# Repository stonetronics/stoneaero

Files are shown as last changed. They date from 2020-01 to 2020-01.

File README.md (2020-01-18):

# stoneaero
Flight controller + transmitter hardware using Arduino Nano, NRF24L01, MPU6050, etc

basic transmitter/receiver code is contained in these folders:

* transmitter
  * basic joystick operation
  * throttle on potentiometer

* receiver
  * basic servo signal forwarding from rf module
  * automatic throttle cut and circular descent when there is no signal received for 1.5s

more advanced functions are contained in receevur/trunsmeetur

* hw
  * eagle files for both pcbs
  * receevur
    * ATmega328p
    * 7 servo channels
    * 3S lipo voltage measurement
    * current measurement
    * MPU9250/MPU6050 header
    * NRF24L01+PA+LNA module
  * trunsmeetur
    * Arduino Mega
    * 16x2 generic lcd
    * buttons for lcd menu
    * NRF24L01+PA+LNA module
    * pinheaders for connecting joysticks, switches etc
    * designed to replace the electronics on a "modelcraft N-6" transmitter

* receevur
  * servo signals
    * airbrake mode for ailerons
  * current/voltage reporting

* trunsmeetur
  * lcd display
    * current/voltage report display
    * joystick settings
  * controls for servo signals

feel free to edit

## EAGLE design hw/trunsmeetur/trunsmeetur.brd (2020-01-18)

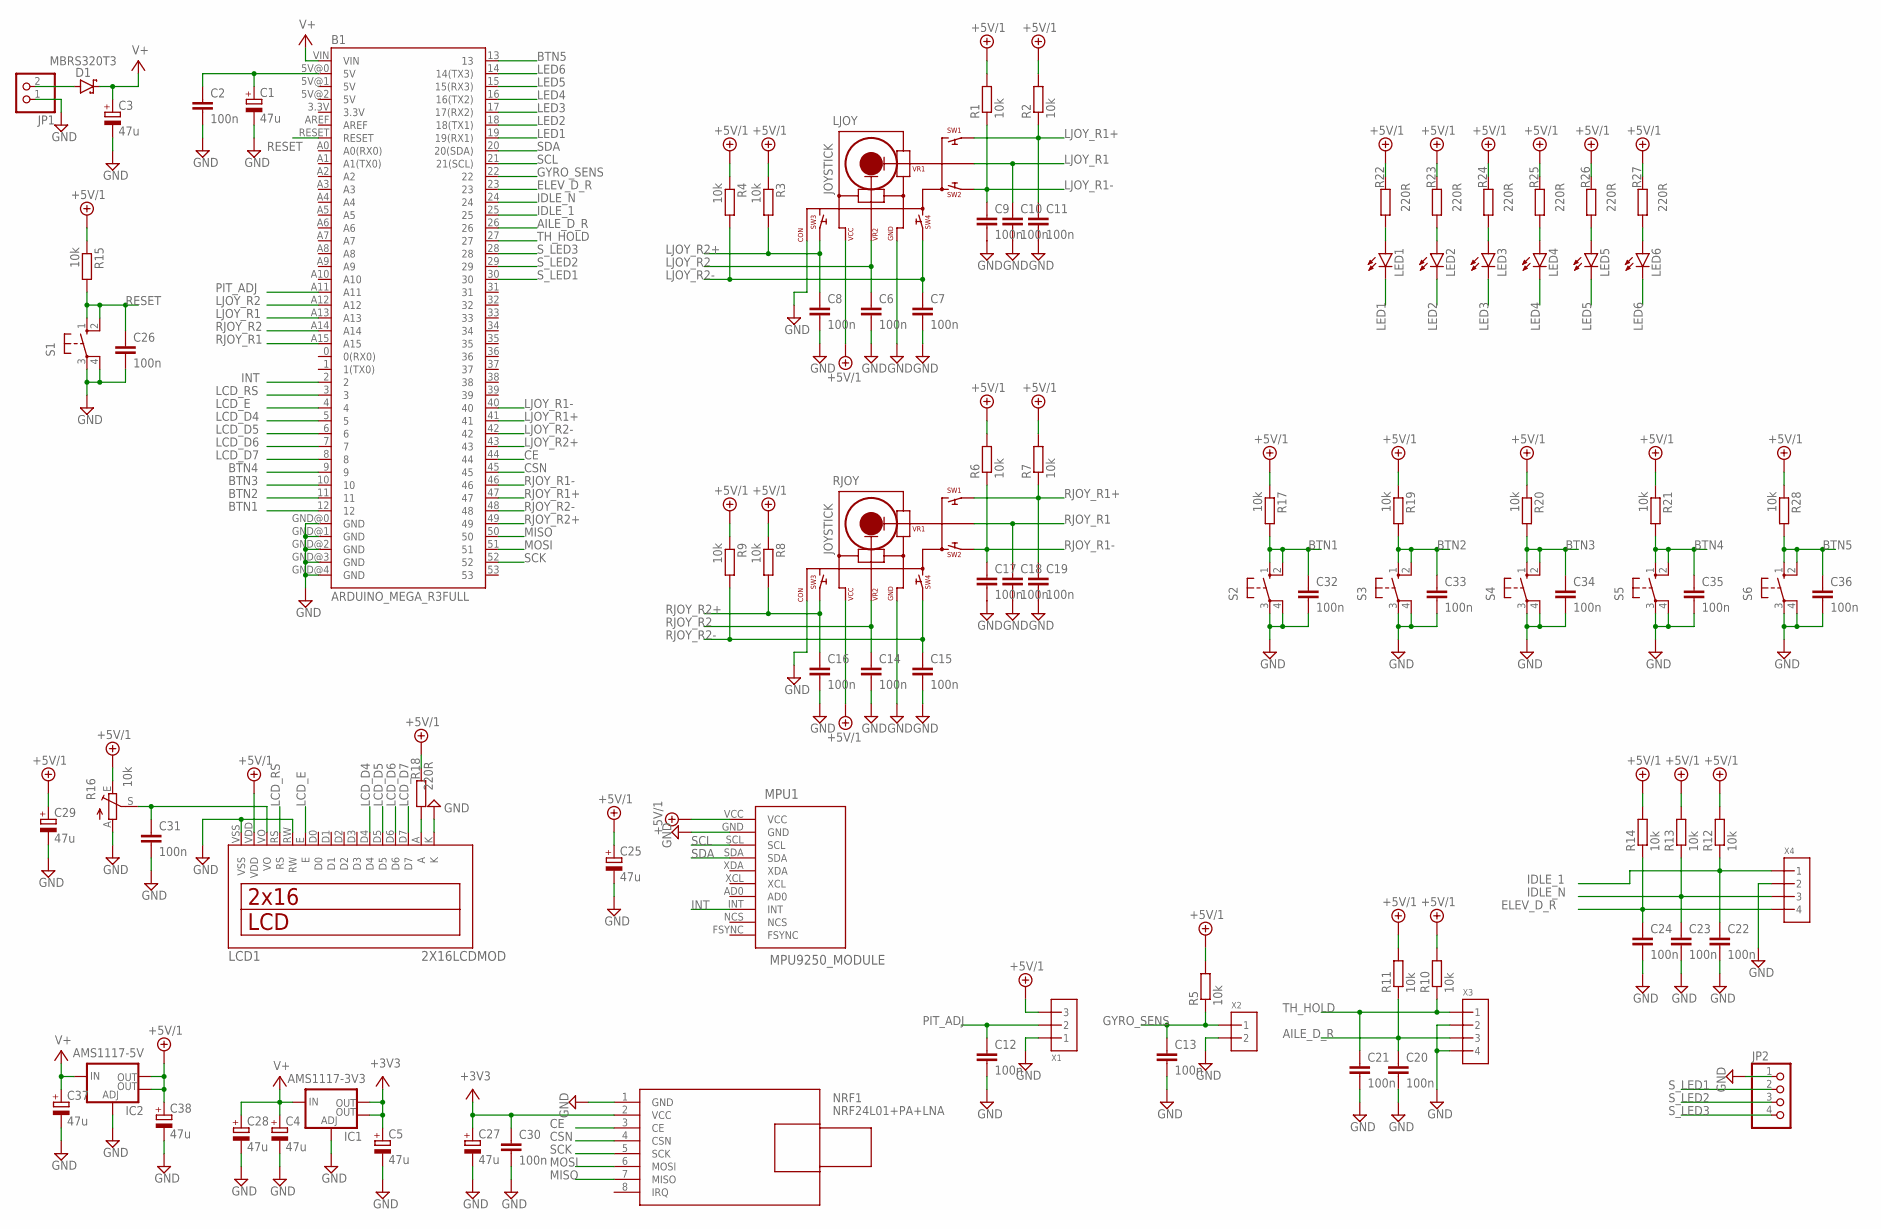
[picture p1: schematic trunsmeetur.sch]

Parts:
B1: ARDUINO_MEGA_R3FULL; ARDUINO_MEGA
C1, C3, C4, C5, C25, C27, C28, C29, C37, C38: 47u; 153CLV-0605
C2, C6, C7, C8, C9, C10, C11, C12, C13, C14, C15, C16, C17, C18, C19, C20, C21, C22, C23, C24, C26, C30, C31, C32, C33, C34, C35, C36: 100n; C0805
D1: MBRS320T3; SMC
IC1: AMS1117-3V3; SOT223
IC2: AMS1117-5V; SOT223
JP1: PINHD-1X2; 1X02
JP2: PINHD-1X4; 1X04
LCD1: 2X16LCDMOD; LCD16X2MOD
LED1, LED2, LED3, LED4, LED5, LED6: LEDCHIPLED_0805; CHIPLED_0805
LJOY: JOYSTICK; JOYSTICKCONNECTOR
MPU1: MPU9250_MODULE
NRF1: NRF24L01+PA+LNA; WIRELESS-NRF24L01-PA-EXT
R1, R2, R3, R4, R5, R6, R7, R8, R9, R10, R11, R12, R13, R14, R15, R17, R19, R20, R21, R28: 10k; M0805
R16: 10k; CA9V
R18, R22, R23, R24, R25, R26, R27: 220R; M0805
RJOY: JOYSTICK; JOYSTICKCONNECTOR
S1, S2, S3, S4, S5, S6: 10-XX; B3F-10XX
X1: 3PIN; 3PINCONNECTOR
X2: 2PIN; 2PINCONNECTOR
X3, X4: 4PIN; 4PINCONNECTOR

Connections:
+3V3: C5.+, C27.+, C30.1, IC1.2 (OUT), IC1.4 (OUT), NRF1.2 (VCC)
+5V/1: C25.+, C29.+, C38.+, IC2.2 (OUT), IC2.4 (OUT), LCD1.VDD, LJOY.VCC, MPU1.VCC, R1.2, R2.2, R3.1, R4.1, R5.2, R6.2, R7.2, R8.1, R9.1, R10.2, R11.2, R12.2, R13.2, R14.2, R15.1, R16.E, R17.1, R18.1, R19.1, R20.1, R21.1, R22.1, R23.1, R24.1, R25.1, R26.1, R27.1, R28.1, RJOY.VCC, X1.3
AILE_D_R: B1.26, C20.1, R11.1, X3.3
BTN1: B1.12, C32.1, R17.2, S2.1 (S), S2.2 (S1)
BTN2: B1.11, C33.1, R19.2, S3.1 (S), S3.2 (S1)
BTN3: B1.10, C34.1, R20.2, S4.1 (S), S4.2 (S1)
BTN4: B1.9, C35.1, R21.2, S5.1 (S), S5.2 (S1)
BTN5: B1.13, C36.1, R28.2, S6.1 (S), S6.2 (S1)
CE: B1.44, NRF1.3 (CE)
CSN: B1.45, NRF1.4 (CSN)
ELEV_D_R: B1.23, C24.1, R14.1, X4.4
GND: B1.GND@0 (GND), B1.GND@1 (GND), B1.GND@2 (GND), B1.GND@3 (GND), B1.GND@4 (GND), C1.-, C2.2, C3.-, C4.-, C5.-, C6.2, C7.2, C8.2, C9.2, C10.2, C11.2, C12.2, C13.2, C14.2, C15.2, C16.2, C17.2, C18.2, C19.2, C20.2, C21.2, C22.2, C23.2, C24.2, C25.-, C26.2, C27.-, C28.-, C29.-, C30.2, C31.2, C32.2, C33.2, C34.2, C35.2, C36.2, C37.-, C38.-, IC1.1 (ADJ), IC2.1 (ADJ), JP1.1, JP2.1, LCD1.K, LCD1.RW, LCD1.VSS, LJOY.CON, LJOY.GND, MPU1.GND, NRF1.1 (GND), R16.A, RJOY.CON, RJOY.GND, S1.3, S1.4 (P1), S2.3, S2.4 (P1), S3.3, S3.4 (P1), S4.3, S4.4 (P1), S5.3, S5.4 (P1), S6.3, S6.4 (P1), X1.1, X2.2, X3.2, X3.4, X4.2
GYRO_SENS: B1.22, C13.1, R5.1, X2.1
IDLE_1: B1.25, C22.1, R12.1, X4.1
IDLE_N: B1.24, C23.1, R13.1, X4.3
INT: B1.2, MPU1.INT
LCD_D4: B1.5, LCD1.D4
LCD_D5: B1.6, LCD1.D5
LCD_D6: B1.7, LCD1.D6
LCD_D7: B1.8, LCD1.D7
LCD_E: B1.4, LCD1.E
LCD_RS: B1.3, LCD1.RS
LED1: B1.19 (19(RX1)), LED1.C
LED2: B1.18 (18(TX1)), LED2.C
LED3: B1.17 (17(RX2)), LED3.C
LED4: B1.16 (16(TX2)), LED4.C
LED5: B1.15 (15(RX3)), LED5.C
LED6: B1.14 (14(TX3)), LED6.C
LJOY_R1: B1.A13, C10.1, LJOY.VR1
LJOY_R1+: B1.41, C11.1, LJOY.SW1, R2.1
LJOY_R1-: B1.40, C9.1, LJOY.SW2, R1.1
LJOY_R2: B1.A12, C6.1, LJOY.VR2
LJOY_R2+: B1.43, C8.1, LJOY.SW3, R3.2
LJOY_R2-: B1.42, C7.1, LJOY.SW4, R4.2
MISO: B1.50, NRF1.7 (MISO)
MOSI: B1.51, NRF1.6 (MOSI)
unnamed: C31.1, LCD1.VO, R16.S
unnamed: D1.A, JP1.2
unnamed: LCD1.A, R18.2
unnamed: LED1.A, R22.2
unnamed: LED2.A, R23.2
unnamed: LED3.A, R24.2
unnamed: LED4.A, R25.2
unnamed: LED5.A, R26.2
unnamed: LED6.A, R27.2
unnamed: B1.5V@0 (5V), C1.+, C2.1
PIT_ADJ: B1.A11, C12.1, X1.2
RESET: B1.RESET, C26.1, R15.2, S1.1 (S), S1.2 (S1)
RJOY_R1: B1.A15, C18.1, RJOY.VR1
RJOY_R1+: B1.47, C19.1, R7.1, RJOY.SW1
RJOY_R1-: B1.46, C17.1, R6.1, RJOY.SW2
RJOY_R2: B1.A14, C14.1, RJOY.VR2
RJOY_R2+: B1.49, C16.1, R8.2, RJOY.SW3
RJOY_R2-: B1.48, C15.1, R9.2, RJOY.SW4
SCK: B1.52, NRF1.5 (SCK)
SCL: B1.21 (21(SCL)), MPU1.SCL
SDA: B1.20 (20(SDA)), MPU1.SDA
S_LED1: B1.30, JP2.2
S_LED2: B1.29, JP2.3
S_LED3: B1.28, JP2.4
TH_HOLD: B1.27, C21.1, R10.1, X3.1
V+: B1.VIN, C3.+, C4.+, C28.+, C37.+, D1.C, IC1.3 (IN), IC2.3 (IN)

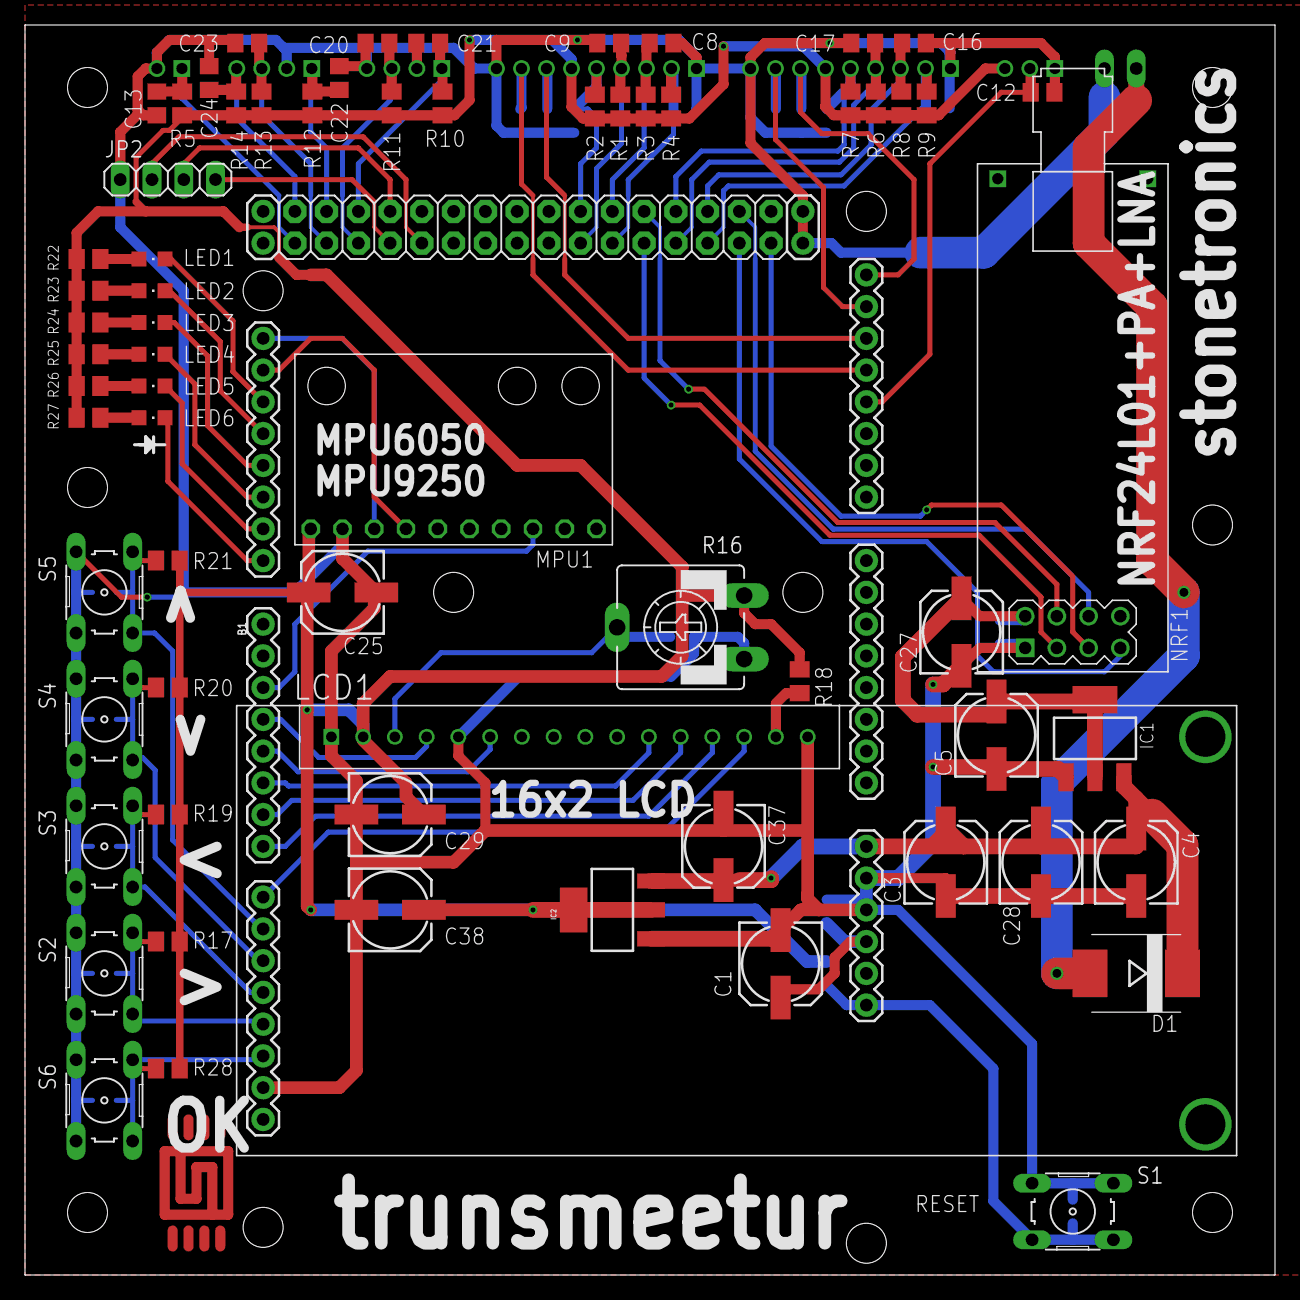
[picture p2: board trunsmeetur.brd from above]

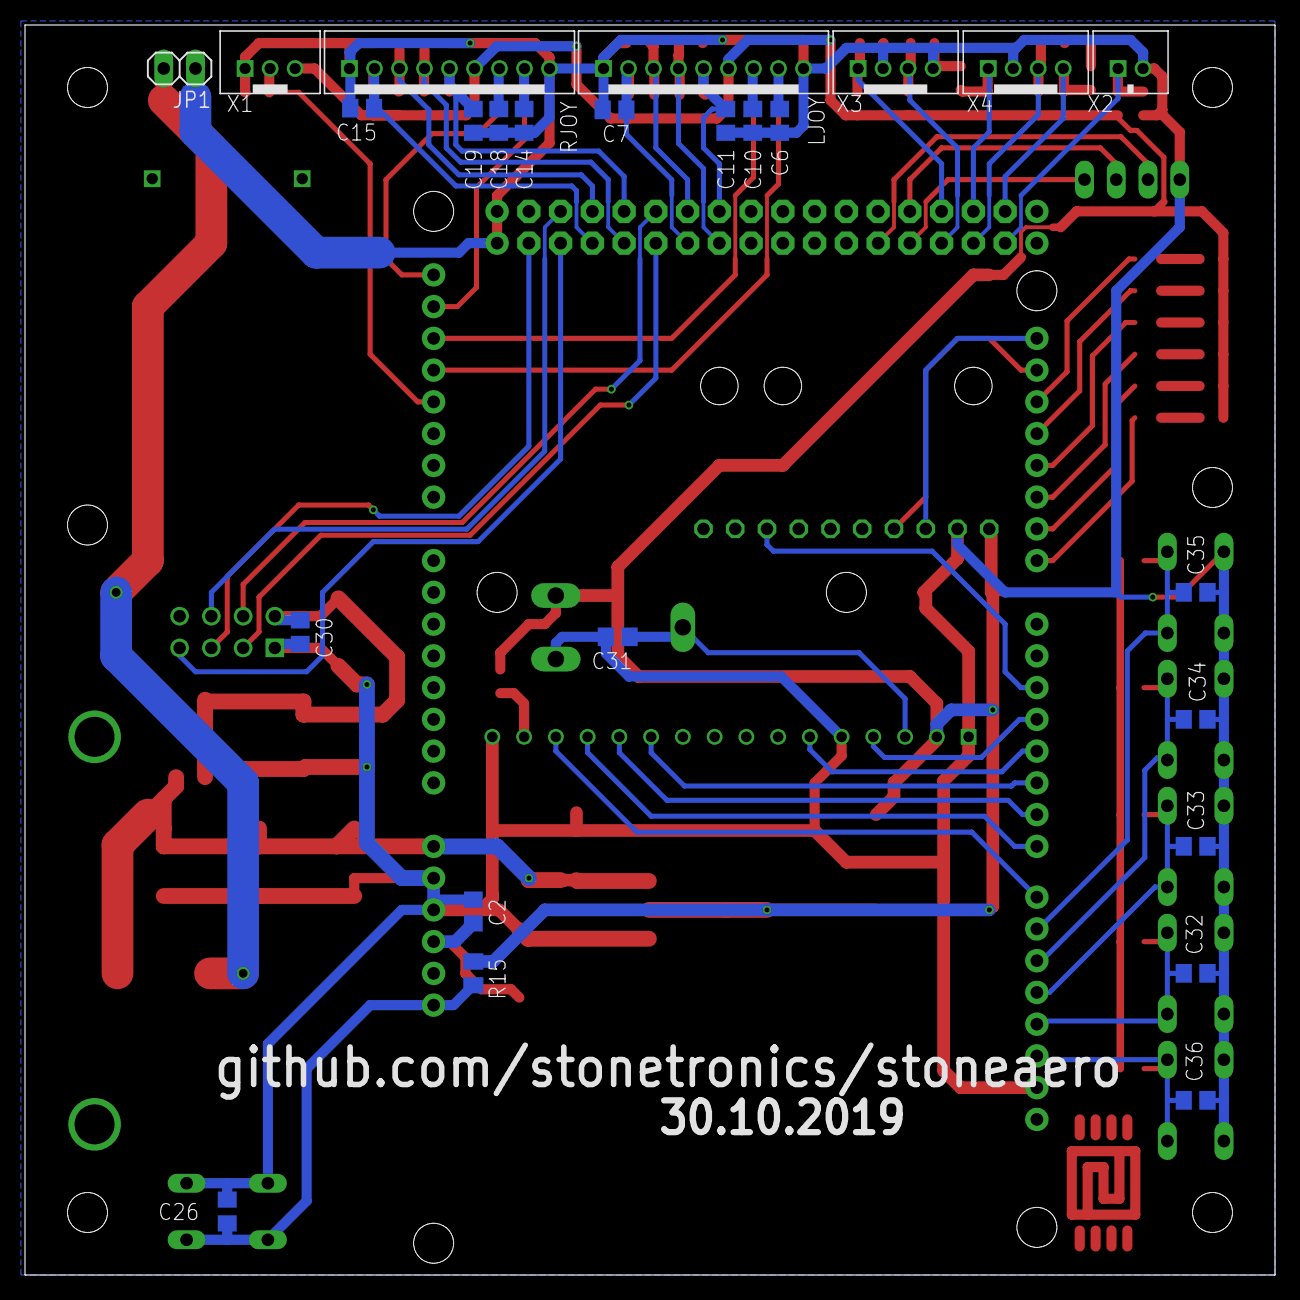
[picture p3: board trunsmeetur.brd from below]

Board: 2 copper layers, 100.0 x 100.0 mm, 93 parts (25 on the bottom side), 62 nets.

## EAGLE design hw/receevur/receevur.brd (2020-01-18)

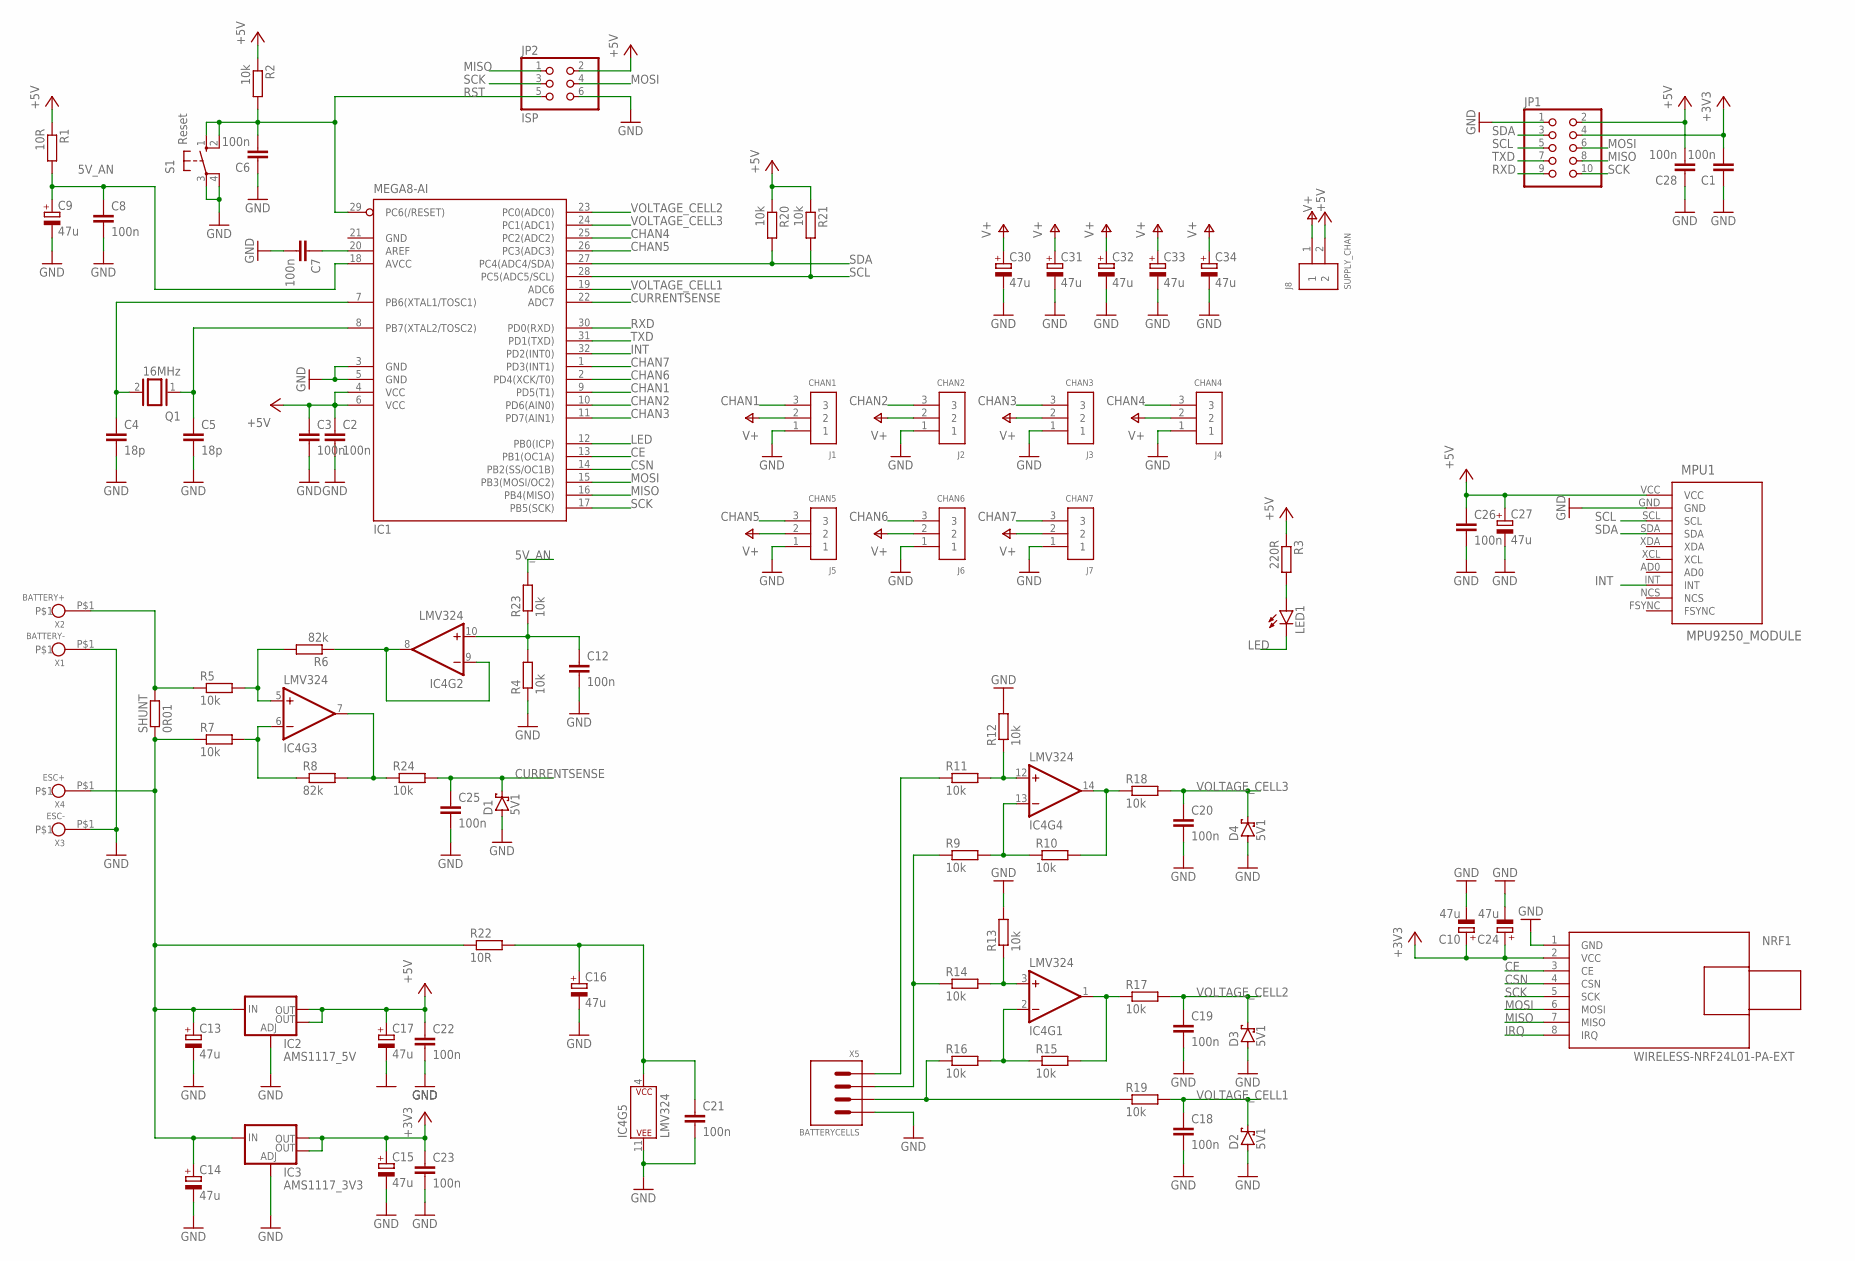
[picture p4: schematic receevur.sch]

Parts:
C1, C2, C3, C6, C7, C8, C12, C18, C19, C20, C21, C22, C23, C25, C26, C28: 100n; C0805
C4, C5: 18p; C0805
C9, C10, C13, C14, C15, C16, C17, C24, C27, C30, C31, C32, C33, C34: 47u; 153CLV-0405
D1, D2, D3, D4: 5V1; SOD323_ST
IC1: MEGA8-AI; TQFP32-08
IC2: AMS1117_5V; SOT223
IC3: AMS1117_3V3; SOT223
IC4: LMV324; SO14
J1: CHAN1; 61300311121
J2: CHAN2; 61300311121
J3: CHAN3; 61300311121
J4: CHAN4; 61300311121
J5: CHAN5; 61300311121
J6: CHAN6; 61300311121
J7: CHAN7; 61300311121
J8: SUPPLY_CHAN; 61300211121
JP1: PINHD-2X5; 2X05
JP2: ISP; 2X03
LED1: LEDCHIP-LED0805; CHIP-LED0805
MPU1: MPU9250_MODULE
NRF1: WIRELESS-NRF24L01-PA-EXT
Q1: 16MHz; QS
R1, R22: 10R; R0805
R2, R4, R5, R7, R9, R10, R11, R12, R13, R14, R15, R16, R17, R18, R19, R20, R21, R23, R24: 10k; R0805
R3: 220R; R0805
R6, R8: 82k; R0805
S1: Reset; B3F-10XX
SHUNT: 0R01; R2512
X1: BATTERY-; SMDSOLDERPAD_5X7
X2: BATTERY+; SMDSOLDERPAD_5X7
X3: ESC-; SMDSOLDERPAD_5X7
X4: ESC+; SMDSOLDERPAD_5X7
X5: BATTERYCELLS; CELLJACK

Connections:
5V_AN: C8.1, C9.+, IC1.18 (AVCC), R1.2, R23.2
+3V3: C1.2, C10.+, C15.+, C23.1, C24.+, IC3.2 (OUT), IC3.4 (OUT), JP1.4, NRF1.2 (VCC)
+5V: C2.1, C3.1, C17.+, C22.1, C26.1, C27.+, C28.2, IC1.4 (VCC), IC1.6 (VCC), IC2.2 (OUT), IC2.4 (OUT), J8.2, JP1.2, JP2.2, MPU1.VCC, R1.1, R2.1, R3.1, R20.1, R21.1
CE: IC1.13 (PB1(OC1A)), NRF1.3 (CE)
CHAN1: IC1.9 (PD5(T1)), J1.3
CHAN2: IC1.10 (PD6(AIN0)), J2.3
CHAN3: IC1.11 (PD7(AIN1)), J3.3
CHAN4: IC1.25 (PC2(ADC2)), J4.3
CHAN5: IC1.26 (PC3(ADC3)), J5.3
CHAN6: IC1.2 (PD4(XCK/T0)), J6.3
CHAN7: IC1.1 (PD3(INT1)), J7.3
CSN: IC1.14 (PB2(SS/OC1B)), NRF1.4 (CSN)
CURRENTSENSE: C25.1, D1.C, IC1.22 (ADC7), R24.2
GND: C1.1, C2.2, C3.2, C4.2, C5.2, C6.1, C7.2, C8.2, C9.-, C10.-, C12.2, C13.-, C14.-, C15.-, C16.-, C17.-, C18.2, C19.2, C20.2, C21.2, C22.2, C23.2, C24.-, C25.2, C26.2, C27.-, C28.1, C30.-, C31.-, C32.-, C33.-, C34.-, D1.A, D2.A, D3.A, D4.A, IC1.3 (GND), IC1.5 (GND), IC1.21 (GND), IC2.1 (ADJ), IC3.1 (ADJ), IC4.11 (P$V-), J1.1, J2.1, J3.1, J4.1, J5.1, J6.1, J7.1, JP1.1, JP2.6, MPU1.GND, NRF1.1 (GND), R4.1, R12.2, R13.2, S1.3, S1.4 (P1), X1.P$1, X3.P$1, X5.P$1
INT: IC1.32 (PD2(INT0)), MPU1.INT
IRQ: NRF1.8 (IRQ)
LED: IC1.12 (PB0(ICP)), LED1.C
MISO: IC1.16 (PB4(MISO)), JP1.8, JP2.1, NRF1.7 (MISO)
MOSI: IC1.15 (PB3(MOSI/OC2)), JP1.6, JP2.4, NRF1.6 (MOSI)
unnamed: C4.1, IC1.7 (PB6(XTAL1/TOSC1)), Q1.2
unnamed: C5.1, IC1.8 (PB7(XTAL2/TOSC2)), Q1.1
unnamed: C7.1, IC1.20 (AREF)
unnamed: LED1.A, R3.2
unnamed: C13.+, C14.+, IC2.3 (IN), IC3.3 (IN), R7.1, R22.1, SHUNT.1, X4.P$1
unnamed: IC4.12 (+IN), R11.2, R12.1
unnamed: C16.+, C21.1, IC4.4 (P$V+), R22.2
unnamed: R5.1, SHUNT.2, X2.P$1
unnamed: IC4.13 (-IN), R9.2, R10.1
unnamed: IC4.8 (OUT), IC4.9 (-IN), R6.1
unnamed: IC4.6 (-IN), R7.2, R8.1
unnamed: IC4.14 (OUT), R10.2, R18.1
unnamed: IC4.3 (+IN), R13.1, R14.2
unnamed: IC4.2 (-IN), R15.1, R16.2
unnamed: IC4.1 (OUT), R15.2, R17.1
unnamed: R11.1, X5.P$4
unnamed: R9.1, R14.1, X5.P$3
unnamed: R16.1, R19.1, X5.P$2
unnamed: C12.1, IC4.10 (+IN), R4.2, R23.1
unnamed: IC4.5 (+IN), R5.2, R6.2
N$$$: IC4.7 (OUT), R8.2, R24.1
RST: C6.2, IC1.29 (PC6(/RESET)), JP2.5, R2.2, S1.1 (S), S1.2 (S1)
RXD: IC1.30 (PD0(RXD)), JP1.9
SCK: IC1.17 (PB5(SCK)), JP1.10, JP2.3, NRF1.5 (SCK)
SCL: IC1.28 (PC5(ADC5/SCL)), JP1.5, MPU1.SCL, R21.2
SDA: IC1.27 (PC4(ADC4/SDA)), JP1.3, MPU1.SDA, R20.2
TXD: IC1.31 (PD1(TXD)), JP1.7
V+: C30.+, C31.+, C32.+, C33.+, C34.+, J1.2, J2.2, J3.2, J4.2, J5.2, J6.2, J7.2, J8.1
VOLTAGE_CELL1: C18.1, D2.C, IC1.19 (ADC6), R19.2
VOLTAGE_CELL2: C19.1, D3.C, IC1.23 (PC0(ADC0)), R17.2
VOLTAGE_CELL3: C20.1, D4.C, IC1.24 (PC1(ADC1)), R18.2

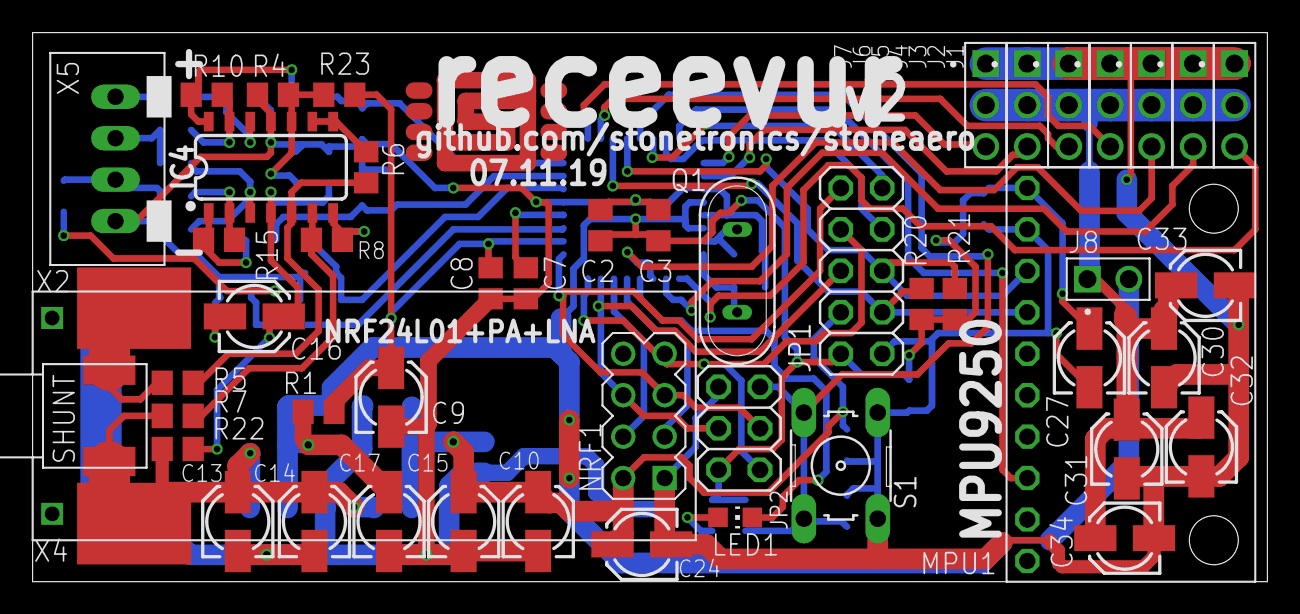
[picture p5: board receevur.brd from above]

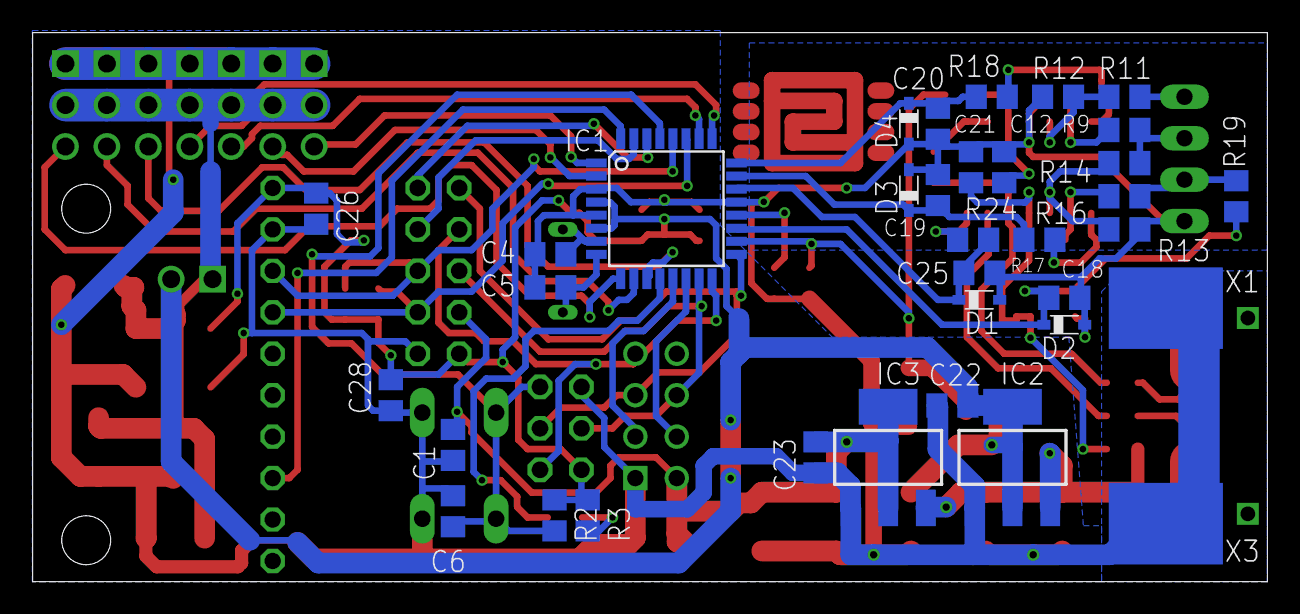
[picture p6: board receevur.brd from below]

Board: 2 copper layers, 75.7 x 33.6 mm, 85 parts (35 on the bottom side), 49 nets.

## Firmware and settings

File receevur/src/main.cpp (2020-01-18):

///avrdude upload command: avrdude -c usbasp -p m328p -u -U flash:w:firmware.hex


//Include needed Libraries at beginning
#include <Arduino.h>
#include <Servo.h>
#include "nRF24L01.h" //NRF24L01 library created by TMRh20 https://github.com/TMRh20/RF24
#include "RF24.h"
#include "SPI.h"
#include "printf.h"

#include "pindef.h"
#include "servodef.h"
#include "Messages.h"
#include "Analog.h"
#include "Monoflop.h"

#define TIMEOUT_DESCENT   2000 //ms   timeout for going into emergency mode

Analog analog;

RF24 radio(CE, CSN); // NRF24L01 used SPI pins + Pin 9 and 10 on the NANO

Monoflop monoflopDescent;
Monoflop monoflopReset;

Servo motor;
Servo rudder;
Servo elevator;
Servo aileronRight;
Servo aileronLeft;

const uint64_t commandPipe = 1; // Needs to be the same for communicating between 2 NRF24L01
const uint64_t reportPipe = 2;

Command command;
Report report;

int16_t motorOffset = 0;
int16_t rudderOffset = 0;
int16_t elevatorOffset = 0;
int16_t aileronsOffset = 0;

void setup(void){

  Serial.begin(115200);
  printf_begin();
  Serial.println("Hullo! Dis eez d receevur!");

  monoflopDescent.setHoldTime(TIMEOUT_DESCENT); //time for emergency routine

  Serial.println("initializing Servos");

  //attach servos
  motor.attach(MOTOR_PIN);
  motor.write(MOTOR_MAX);
  rudder.attach(RUDDER_PIN);
  rudder.write(90);
  elevator.attach(ELEVATOR_PIN);
  elevator.write(90);
  aileronRight.attach(AILERONRIGHT_PIN);
  aileronRight.write(90);
  aileronLeft.attach(AILERONLEFT_PIN);
  aileronLeft.write(90);

  //init led
  pinMode(LED, OUTPUT);
  //blink it
  for (uint8_t i = 0; i < 5; i++)
  {
    digitalWrite(LED, LOW);
    delay(300);
    digitalWrite(LED, HIGH);
    delay(120);
  }
  digitalWrite(LED, LOW);

  Serial.println("Initializing Analog measurements");
  analog.setCellCalibration(0, 29, 6, 0);
  analog.setCellCalibration(1, 29, 6, 0);
  analog.setCellCalibration(2, 29, 6, 0);
  analog.setCurrentCalibration(11689,101,-59255);

  Serial.println("Initializing radio");

  radio.begin(); // Start the NRF24L01
  radio.openWritingPipe(reportPipe);
  radio.openReadingPipe(1, commandPipe); //get ready to receive
  radio.setDataRate( RF24_250KBPS ) ;
  radio.setPALevel( RF24_PA_MAX ) ;
  radio.setChannel(0x34);
  radio.enableDynamicPayloads() ;
  radio.enableAckPayload();               // not used here
  radio.setRetries(0, 15);                // Smallest time between retries, max no. of retries
  radio.setAutoAck( true ) ;
  radio.printDetails();                   // Dump the configuration of the rf unit for debugging
  radio.powerUp();
  radio.startListening();
}

void loop(void){

  if (!monoflopDescent.output()) //emergency - no transmitter signal received for TIMEOUT_DESCENT
  {
    Serial.println("Hmmst! Nopheeng receevhde. Eemurgance..");
    //cut motor
    motor.write(MOTOR_MIN); //todo: does the motor need throttle for safe descent? - probably
  }



  while (radio.available())
  {
    monoflopDescent.trigger();
    radio.read(&command, sizeof(command));
    switch (command.mode)
    {
      case 'c':
        if (command.controlByte & 0x01)
        { //flaps mode
          aileronRight.write(map(((command.roll) + aileronsOffset),-90,90,AILERONRIGHT_MIN,90));
          aileronLeft.write(map((-1)*((command.roll) + aileronsOffset),-90,90,AILERONLEFT_MIN,90));
        } else { //normal mode
          aileronRight.write(map(((command.roll) + aileronsOffset),-90,90,AILERONRIGHT_MIN,AILERONRIGHT_MAX));
          aileronLeft.write(map((-1)*((command.roll) + aileronsOffset),-90,90,AILERONLEFT_MIN,AILERONLEFT_MAX));
        }
        motor.write(map(((command.throttle) + motorOffset),0,100,MOTOR_MIN,MOTOR_MAX));
        rudder.write(map(((command.yaw) + rudderOffset),-90,90,RUDDER_MIN,RUDDER_MAX));
        elevator.write(map(((command.pitch) + elevatorOffset),-90,90,ELEVATOR_MIN,ELEVATOR_MAX));
        break;

      case 'o':
        //motorOffset = command.throttle;
        rudderOffset = command.yaw;
        elevatorOffset = command.pitch;
        aileronsOffset = command.roll;

      default:
        break;
    }

    //command received and processed - transmit report package
    report.current = analog.getCurrent();
    analog.getCells(&(report.cellVoltage[0]));
    radio.stopListening();
    radio.write(&report, sizeof(report)); // Send value through NRF24L01
    radio.startListening();
  }

}

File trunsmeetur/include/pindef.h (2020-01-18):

#ifndef __PINDEF_H__
#define __PINDEF_H__


//JOYSTICKS

#define LJOY_R1       A13
#define LJOY_R1PLUS   41
#define LJOY_R1MINUS  40

#define LJOY_R2       A12
#define LJOY_R2PLUS   43
#define LJOY_R2MINUS  42

#define RJOY_R1       A15
#define RJOY_R1PLUS   47
#define RJOY_R1MINUS  46

#define RJOY_R2       A14
#define RJOY_R2PLUS   49
#define RJOY_R2MINUS  48


//PCB BUTTONS

#define BTN1    12
#define BTN2    11
#define BTN3    10
#define BTN4    9
#define BTN5    13

//readability
#define BTN_UP      BTN4
#define BTN_DOWN    BTN3
#define BTN_LEFT    BTN2
#define BTN_RIGHT   BTN1
#define BTN_OK      BTN5


//PCB LEDS (0-active)

#define LED1  19
#define LED2  18
#define LED3  17
#define LED4  16
#define LED5  15
#define LED6  14


//pitch adj poti

#define PIT_ADJ   A11


//finger switches

#define GYRO_SENS   (22)
#define ELEV_D_R    (23)
#define IDLE_N      (24)
#define IDLE_1      (25)
#define AILE_D_R    (26)
#define TH_HOLD     (27)


//case LEDS (1-active)

#define S_LED1    30
#define S_LED2    29
#define S_LED3    28

//readability
#define S_CHARGE  S_LED2
#define S_HACK    S_LED3
#define S_POWER   S_LED1

//nRF24L01+PA+LNA connection

#define CE      44
#define CSN     45


//MPU9250 interrupt line

#define INT     2


//LCD connection

#define LCD_RS    3
#define LCD_E     4
#define LCD_D4    5
#define LCD_D5    6
#define LCD_D6    7
#define LCD_D7    8


#endif

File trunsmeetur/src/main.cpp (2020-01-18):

/*modify and use as you like*/


//Include needed Libraries at beginning
#include <Arduino.h>
#include <EEPROM.h>
#include "pindef.h"
#include "DataTypes.h"
#include "LiquidCrystal.h"
#include "LCDMenu.h"
#include "Button.h"
#include "Joystick.h"
#include "IdleSwitch.h"
#include "FingerSwitch.h"
#include "ControlInterface.h"
#include "Messages.h"
#include "nRF24L01.h" //NRF24L01 library created by TMRh20 https://github.com/TMRh20/RF24
#include "RF24.h"
#include "SPI.h"
#include "printf.h"
#include "CommunicationHandler.h"

#define VERBOSE   //uncomment to get verbose feedback on serial
//#define ANALOGAXIS_DEBUG  //uncomment to get all analog axis on output for calibration

//Instantiate Hardware
//Menu Buttons
Button okBtn(BTN_OK);
Button rightBtn(BTN_RIGHT);
Button leftBtn(BTN_LEFT);
Button downBtn(BTN_DOWN);
Button upBtn(BTN_UP);

//joystick offset buttons
Button lJoyR1IncBtn(LJOY_R1PLUS);
Button lJoyR1DecBtn(LJOY_R1MINUS);
Button lJoyR2IncBtn(LJOY_R2PLUS);
Button lJoyR2DecBtn(LJOY_R2MINUS);
Button rJoyR1IncBtn(RJOY_R1PLUS);
Button rJoyR1DecBtn(RJOY_R1MINUS);
Button rJoyR2IncBtn(RJOY_R2PLUS);
Button rJoyR2DecBtn(RJOY_R2MINUS);

//LCD display
LiquidCrystal lcd(LCD_RS, LCD_E, LCD_D4, LCD_D5, LCD_D6, LCD_D7);

//NRF24L01+ radio module
RF24 radio(CE, CSN);


//Shared Data
GlobalData globalData;

//instantiate software modules


int16_t lJoyYVal;
Joystick lJoyY(LJOY_R1, &lJoyR1IncBtn, &lJoyR1DecBtn, &(globalData.persistent.controlInterfaceConfiguration.throttleJoyConf), &lJoyYVal);
int16_t lJoyXVal;
Joystick lJoyX(LJOY_R2, &lJoyR2IncBtn, &lJoyR2DecBtn, &(globalData.persistent.controlInterfaceConfiguration.yawJoyConf), &lJoyXVal);
int16_t rJoyYVal;
Joystick rJoyY(RJOY_R1, &rJoyR1IncBtn, &rJoyR1DecBtn, &(globalData.persistent.controlInterfaceConfiguration.pitchJoyConf), &rJoyYVal);
int16_t rJoyXVal;
Joystick rJoyX(RJOY_R2, &rJoyR2IncBtn, &rJoyR2DecBtn, &(globalData.persistent.controlInterfaceConfiguration.rollJoyConf), &rJoyXVal);
IdleSwitchState swIdle; //state variable to store the switch value. it can be read from other modules to be used
IdleSwitch switchIdle(IDLE_1, IDLE_N, &swIdle);
uint8_t swElev;
FingerSwitch switchElev(ELEV_D_R, 0, &swElev); //dont invert switch
uint8_t swAile;
FingerSwitch switchAile(AILE_D_R, 0, &swAile);
uint8_t swThHold;
FingerSwitch switchThHold(TH_HOLD, 0, &swThHold);
uint8_t swGyroSens;
FingerSwitch switchGyroSens(GYRO_SENS, 0, &swGyroSens);
int16_t pitAdjVal;
Poti pitAdjPoti(PIT_ADJ, &(globalData.persistent.controlInterfaceConfiguration.pitAdjConf), &pitAdjVal);

ControlInterface controlInterface(&rJoyX, &rJoyY, &lJoyX, &lJoyY, &switchIdle, &switchElev, &switchAile, &switchThHold, &switchGyroSens, &pitAdjPoti);

LCDMenu menu(&lcd, &okBtn, &rightBtn, &leftBtn, &downBtn, &upBtn, &controlInterface, &globalData);

CommunicationHandler communicationHandler(&radio, &globalData);

void setup(void)
{
  //init global Data

  globalData.lastReport = {0, {0,0,0}};

  /* sample conf, uncomment this the first upload to write it into eeprom
  globalData.persistent.controlInterfaceConfiguration = {   {0, 1023, 0, -90, 90},
                                                            {0, 1023, 0, -90, 90},
                                                            {0, 1023, 0, -90, 90},
                                                            {0, 1023, 0, 0, 100},
                                                            {0, 1023, 0, 1023}  };
  //write eeprom values the first time
  EEPROM.put(PERSISTENTDATA_EEPROM_ADDR, globalData.persistent); */

  //set leds on pcb
  pinMode(LED1, OUTPUT);
  pinMode(LED2, OUTPUT);
  pinMode(LED3, OUTPUT);
  pinMode(LED4, OUTPUT);
  pinMode(LED5, OUTPUT);
  pinMode(LED6, OUTPUT);
  digitalWrite(LED1, HIGH);
  digitalWrite(LED2, HIGH);
  digitalWrite(LED3, HIGH);
  digitalWrite(LED4, HIGH);
  digitalWrite(LED5, HIGH);
  digitalWrite(LED6, HIGH);

  //set case leds
  pinMode(S_POWER, OUTPUT);
  pinMode(S_CHARGE, OUTPUT);
  pinMode(S_HACK, OUTPUT);
  digitalWrite(S_POWER, HIGH);     //indicate power
  digitalWrite(S_CHARGE, LOW);
  digitalWrite(S_HACK, LOW);

  Serial.begin(115200);
  #ifdef VERBOSE
  Serial.println("ohw hullow! dis eez dee NRF24L01 trunsmeetur");
  #endif
  printf_begin();

  communicationHandler.initRadio();
  #ifdef VERBOSE
  communicationHandler.printRadioDetails();
  #endif
  digitalWrite(S_HACK, HIGH); //indicate radio startup

  //read eeprom values
  EEPROM.get(PERSISTENTDATA_EEPROM_ADDR, globalData.persistent);

  //first update of the conrol interface
  controlInterface.update();

}

void loop(void){
  ControlVector c;

  //Serial.println("loop");
  menu.update();
  controlInterface.update();
  communicationHandler.updateReport();
  c.thrust = lJoyYVal;
  c.roll = rJoyXVal;
  c.pitch = rJoyYVal;
  c.yaw = lJoyXVal;
  communicationHandler.sendCommand(generateControlCommand(c, swThHold));

  #ifdef ANALOGAXIS_DEBUG
  Serial.print("lY: ");
  Serial.print(lJoyYVal);
  Serial.print(" lYOffs: ");
  Serial.print(globalData.persistent.controlInterfaceConfiguration.throttleJoyConf.offset);
  Serial.print(" lX: ");
  Serial.print(lJoyXVal);
  Serial.print(" lXOffs: ");
  Serial.print(globalData.persistent.controlInterfaceConfiguration.yawJoyConf.offset);
  Serial.print(" rY: ");
  Serial.print(rJoyYVal);
  Serial.print(" rYOffs: ");
  Serial.print(globalData.persistent.controlInterfaceConfiguration.pitchJoyConf.offset);
  Serial.print(" rX: ");
  Serial.print(rJoyXVal);
  Serial.print(" rXOffs: ");
  Serial.print(globalData.persistent.controlInterfaceConfiguration.rollJoyConf.offset);
  Serial.print(" swIdle: ");
  Serial.print(swIdle);
  Serial.print(" swElev:");
  Serial.print(swElev);
  Serial.print(" swAile: ");
  Serial.print(swAile);
  Serial.print(" swThHold: ");
  Serial.print(swThHold);
  Serial.print(" swGyroSens: ");
  Serial.print(swGyroSens);
  Serial.print(" pitAdj: ");
  Serial.println(pitAdjVal);
  delay(200);
  #endif

}

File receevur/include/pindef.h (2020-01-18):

#ifndef __PINDEF_H__
#define __PINDEF_H__

////////////////////////////////
/// HARDWARE PIN DEFINITIONS ///
////////////////////////////////

//analog pins
#define VOLTAGE_CELL1   A6
#define VOLTAGE_CELL2   A0
#define VOLATGE_CELL3   A1
#define CURRENTSENSE    A7

//output channels
#define CHAN1 5
#define CHAN2 6
#define CHAN3 7
#define CHAN4 A2
#define CHAN5 A3
#define CHAN6 4
#define CHAN7 3

//mpu interface
#define INT 2

//nRF24L01+ interface
#define CE    9
#define CSN   10

//LED
#define LED   8

#endif

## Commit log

2019-06-13 add servo rate control to transmitter
2020-01-18 add pcb files and better firmware
    [receevur.brd, receevur.sch, trunsmeetur.brd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]

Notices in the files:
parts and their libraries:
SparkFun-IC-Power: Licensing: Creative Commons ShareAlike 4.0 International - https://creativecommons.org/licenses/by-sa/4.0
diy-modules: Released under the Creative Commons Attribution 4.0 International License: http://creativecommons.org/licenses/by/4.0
